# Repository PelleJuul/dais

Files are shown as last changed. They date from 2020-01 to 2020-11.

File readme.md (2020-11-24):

# The Daïs: A Haptically Enabled Electronical Instrument

A picture of the dais

The daïs is an open source *new interface for musical expression* (NIME).
The daïs main feature is a disk that is suspended by elastic string.
The instrument is played by pushing down and moving the disk around.
The position and angle of the disk is captured by sensors and can be used to control sound synthesis algorithms or audio effects.

Multiple parameters to be controlled with a single movement, and the gestures afforded by the instrument result in a performative playing style.
The disk is haptically enabled using vibrotactile transducers that facilitate an intimate playing experience.

The Daïs was presented at [NIME 2020](https://www.nime.org/proceedings/2020/nime2020_paper119.pdf) and was later featured on the [Bela blog](https://blog.bela.io/2020/10/30/dais-haptic-feedback-instrument-pelle-christensen/). See also the [video](https://www.youtube.com/watch?v=Zl-xNjUgyLA) made for the blog post.

## About this Repository

This repository contains everything you need to build your own daïs.

The *source* folder contains a ready-to-use Bela application that will read the sensors and produce a synthesized bowed string sound.

*dais_mechanical_design.scad* is an OpenSCAD file of the mechanical design of the daïs that can be used to generate files for laser cutting.

## Building a daïs

To build a daïs you will need the following tools and software

* [OpenSCAD](https://www.openscad.org/downloads.html).
* A vector drawing program such as Adobe Illustrator, CorelDraw or [Inkscape](https://inkscape.org/) (free).
* A laser cutter.
* A soldering iron.
* Misc. small tools such as scissors, cutter, and pliers.

The electronics parts you need are

* A [Bela](https://bela.io/).
* An APDS9900 breakout board (e.g. the one from [Sparkfun](https://www.sparkfun.com/products/12787)).
* A Bosch Sensortec BNO055 breakout board (e.g. [this one on ebay](https://www.ebay.com/itm/BNO055-MCU-9DOF-Intelligent-9Axis-Attitude-Sensor-Angle-gyroscope-Accelerometer/323248036779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)).
* A small stereo amplifier board ([such as this one](https://www.banggood.com/TPA3118-2x30W-8-26V-DC-Stereo-Bluetooth-Digital-Amplifier-Board-p-1095250.html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)).
* A surface transducer ([like this one](https://www.sparkfun.com/products/10975)).
* Some wire and optionally some Bela-compatible Molex connectors.

Other matrials needed are

* Solder.
* SuperGlue.
* Strips.
* Elastic string, 1m, around 3mm in diameter.
* Leather straps or string, around 2m.
* Duct tape (don't know for what exactly but you will probably need it).

The parts and materials should be assembled like so:

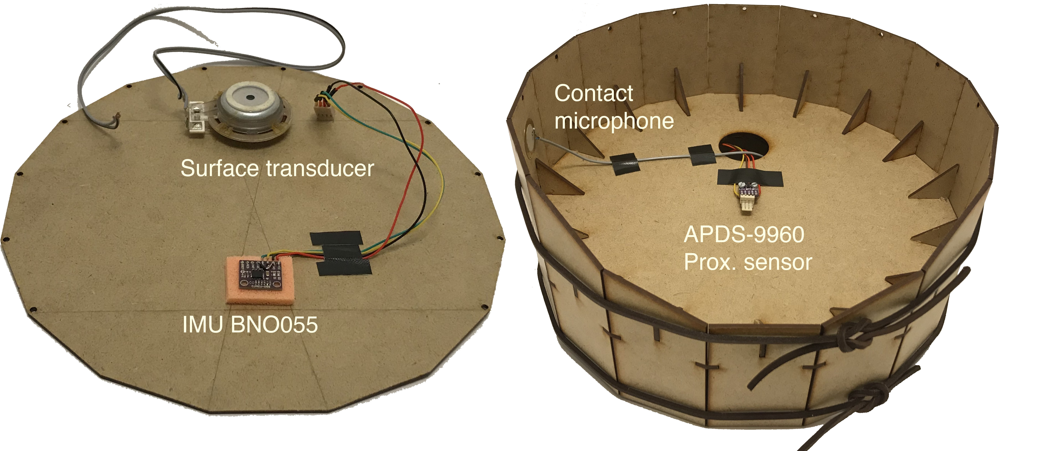
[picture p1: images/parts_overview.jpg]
Picture with an overview of the placements of the parts


## Whish list

This repository is far from perfect, these are the things needed to make it good:

* Add desciption on how to get the source code onto the bela (use the *push* script in the *source* folder)
* Add descriptions of the parameter mapping of the software.
* Add the paper (when its done).
* Through build instruct with step-by-step pictures.
* Clean up code and add comments.
* Make a video of the build process and the instrument being played.

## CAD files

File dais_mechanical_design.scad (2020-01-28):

// CHECK BEFORE PRINTING:
// - Are all dimensions correct?
// - Is material thickness correct?
// - Is kerf correct?
$fn = 50;

mt = 3; // Material thickness
// Kerf tip: Keep fingers the "right" size and make the slots a big smaller.
kerf = 0.125;
explode = false;
kc = 2; // Knoll clearance

numFaces = 16; // Number of edges on base plate
baseRadius = 150;
diskRadius = baseRadius - 20;

// If we call ngon directly with the specified baseRadius our disk will be too small.
// We want baseRadius to be the distance from the center to the middle of one of the edges.
// Here we compute the radius we need to acheive that.
trueBaseRadius = baseRadius * (1 / cos(0.5 * (360 / numFaces)));
trueDiskRadius = diskRadius * (1 / cos(0.5 * (360 / numFaces)));

wallUpper = 80; // Upper height of wall
wallLower = 60; // Lower hight of wall
wallWidth = norm([trueBaseRadius - mt, 0] - [(trueBaseRadius - mt) * cos(360 / numFaces), (trueBaseRadius- mt) * sin(360 / numFaces)]);
wallMiddleWidth = 0.8 * wallWidth;
wallSupportWidth = 30;
cutoutHeight = 1 - wallSupportWidth / wallUpper;
cutoutWidth = 5 * (1 / numFaces);
wireRadius = 1.5;
mountHeight = mt;
routingHoleRadius = 20;

function ex(enable) = (enable && explode) ? explodeAmount : 0;
function cutout(x, w, h) = x < w ? 1 - h * sin(180 * (x / w)) : 1;

module mount(tool = false, knoll = false)
{
    module mountInner()
    {
        union()
        {
            translate([-(baseRadius - mt), 0, 0])
            translate([-mt, -0.5 * 0.5 * wallWidth, 0])
            cube([mt, 0.5 * wallWidth, mt]);

            translate([baseRadius - mt, 0, 0])
            translate([0, -0.5 * 0.5 * wallWidth, 0])
            cube([mt, 0.5 * wallWidth, mt]);

            translate([-(baseRadius - mt), -0.5 * wallWidth, 0])
                cube([2 * baseRadius - 2 * mt, wallWidth, mt]);
        }
    }
    
    if (tool)
    {
        w = 0.5 * wallWidth - 2 * kerf;
        h = mt - 2 * kerf;
        translate([0, 0, mountHeight])
        translate([0, 0.5 * (wallWidth - w), 0])
        translate([0, 0, 0.5 * (mt - h)])
            cube([mt, w, h]);

    }
    else
    {
        color("pink")
        
        if (knoll)
        {
            translate([(trueBaseRadius + mt), 0.5 * wallWidth, 0]) 
            mountInner();
        }
        else
        {
            rotate([0, 0, -2 * (360 / numFaces)])
            translate([0, 0, mountHeight])
                mountInner();
        }
    }
}
module ngon(numFaces, radius, height)
{
    p = [for (i = [0:numFaces-1]) [radius * cos(i * (360 / numFaces)), radius * sin(i * (360 / numFaces))]];
    echo(p);
    linear_extrude(height)
        polygon(p);
}

module wallSupport(tool = false, knoll = false)
{   
    e = ex(!tool);

    width = wallSupportWidth;
    height = width;
    k = tool ? kerf : 0;
    fingerLength = (width * 0.5) - (tool ? 2 * kerf : 0);
    fingerWidth = mt - (tool ? 2 * kerf : 0);
    fingerHeight = mt;
    
    module finger()
    {
        translate([0, 0.5 * (mt - fingerWidth), 0]) // Center on part y axis (in case this is a tool)
        translate([-fingerLength - 0.5 * (width - fingerLength), 0, 0]) // Center on part x axis
        translate([0, 0, -fingerHeight]) // Flush with x axis
        cube([fingerLength, fingerWidth, fingerHeight]);
    }
    
    color("pink")
    union()
    {
        if (true)
        {
            rotate([-90, 0, 0]) // Turn upright
            linear_extrude(mt)
                polygon([[0, 0], [0, -height], [-width, 0]]);
        }
        
        finger();
        
        translate([fingerHeight, 0, 0])
        rotate([0, 90, 0])
            finger();
    }
}

module wall(a = wallUpper, b = wallUpper, slot = false, tool = false)
{
    if (tool)
    {
        
        translate([0, 0.5 * (wallWidth - (wallMiddleWidth - 2 * kerf)), wallLower])
                cube([mt, wallMiddleWidth - 2 * kerf, mt]);
    }
    else
    {
        difference()
        {
            union()
            {
                // Lower part
                cube([mt, wallWidth, wallLower + kerf]);
                
                // Middle part
                translate([0, 0.5 * (wallWidth - wallMiddleWidth), wallLower + kerf])
                    cube([mt, wallMiddleWidth, mt - 2 * kerf]);
                
                // Upper part
                translate([0, 0, wallLower + mt - kerf])
                translate([mt, 0, 0])
                rotate([0, -90, 0])
                linear_extrude(mt)
                polygon([
                    [0, 0],
                    [a, 0],
                    [b, wallWidth],
                    [0, wallWidth]]);
            }
            
            // Hole for wire
            if (a == b && a == wallUpper)
            {
                translate([0, 0, wallLower + mt - kerf + 0.5 * (a + b) - 2 * wireRadius])
                translate([0, 0.5 * wallWidth, 0])
                rotate([0, 90, 0]) // Rotate to correct orientation
                cylinder(mt, wireRadius, wireRadius);
            }
            
            translate([0, 0, wallLower + mt - kerf]) // Move to meet base plate
            translate([0, 0.5 * wallWidth, 0]) // Center on wall
            translate([0, -0.5 * mt, 0]) // Center on y-axis
                wallSupport(tool = true);
            
            if (slot)
            {
                mount(tool = true);
            }
        }
    }
}

module wallWithSupport(a, b, slot, tool = false, knoll = false)
{
    wall(a, b, slot, tool);
    
    if (tool)
    {
        translate([0, 0, wallLower + mt]) // Move to meet base plate
        translate([0, 0.5 * wallWidth, 0]) // Center on wall
        translate([0, -0.5 * mt, 0]) // Center on y-axis
            wallSupport(tool);
    }
    else
    {
        if (knoll)
        {
            translate([0, 0, wallLower + mt + max(a, b) + kc - kerf])
            translate([0, mt, mt])
            rotate([0, 0, -90])
                wallSupport(tool);
        }
        else
        {
            translate([0, 0, wallLower + mt - kerf]) // Move to meet base plate
            translate([0, 0.5 * wallWidth, 0]) // Center on wall
            translate([0, -0.5 * mt, 0]) // Center on y-axis
                wallSupport(tool);
        }
    }
}

module walls(tool = false, knoll = false)
{
    for (i = [0:numFaces-1])
    {
        a = i * (360 / numFaces);
        x1 = i / numFaces;
        x2 = (i+1)/ numFaces;
        echo(x1, x2);
        h1 = wallUpper * cutout(x1, cutoutWidth, cutoutHeight);
        h2 = wallUpper * cutout(x2, cutoutWidth, cutoutHeight);
        
        if (knoll)
        {
            translate([0, 0, mt])
            translate([0, i * (wallWidth + kc), 0])
            rotate([0, 90, 0])
                wallWithSupport(h1, h2, i == 6 || i == numFaces - 2, tool, knoll=true);
        }
        else
        {

            rotate([0, 0, a]) // Rotate to appropriate edge
            translate([-mt, 0, 0]) // Move flush to edge
            translate([baseRadius, 0, 0]) // Move to edge of base plate
            translate([0, -0.5 * wallWidth, 0]) // center on y axis
                wallWithSupport(h1, h2, i == 6 || i == numFaces - 2, tool);
        }
    }
}

module base()
{     
    color("green")
    
    difference()
    {
        rotate([0, 0, 0.5 * (360 / numFaces)])
            ngon(numFaces, trueBaseRadius, mt);
        
        translate([0, 0, -wallLower]) // Move down to collide with base
            walls(tool = true);
        
        translate([-0.3 * trueBaseRadius, -0.3 * trueBaseRadius, 0, ])
            cylinder(mt,routingHoleRadius, routingHoleRadius);
        
        // Cutouts for proximity sensor
        rotate([0, 0, -45])
        {
            translate([-4.5, 0, 0])
                cylinder(mt, 1.5, 1.5);
            translate([4.5, 0, 0])
                cylinder(mt, 1.5, 1.5);
        }
    }
}

module disk()
{
    rotate([0, 0, 0.5 * (360 / numFaces)])
    difference()
    {
        ngon(numFaces, trueDiskRadius, mt);
        
        for (i = [4:numFaces-1])
        {
            rotate([0, 0, i * (360 / numFaces)])
            translate([trueDiskRadius - 2 * wireRadius, 0, 0])
                cylinder(mt, wireRadius, wireRadius);
        }
    }
}

// The knoll flag enables layout of all the parts for laser cutting. Set to
// false to see a 3D model of the dais design.
knoll = true;

if (knoll)
{
    projection()
    {
        walls(knoll = true);
        x1 = wallLower + wallUpper + mt - kerf + wallSupportWidth + 2 * kc;
        translate([x1, 0, 0])
            mount(knoll = true);
        
        x2 = x1 + kc + 2 * trueBaseRadius + baseRadius + 2 * mt;
        
        translate([x2, baseRadius, 0])
            base();
        
        x3 = x2 + kc + 2 * baseRadius;
        translate([x3, diskRadius, 0])
        disk();
    }
}
else
{
    walls();
    mount();
    translate([0, 0, wallLower])
        base();
    translate([0, 0, wallLower + mt + wallUpper])
        disk();    
}
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

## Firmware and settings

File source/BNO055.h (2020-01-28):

/***************************************************************************
  This is a library for the BNO055 orientation sensor
  Designed specifically to work with the Adafruit BNO055 Breakout.
  Pick one up today in the adafruit shop!

  ------> http://www.adafruit.com/products

  These sensors use I2C to communicate, 2 pins are required to interface.

  Adafruit invests time and resources providing this open source code,
  please support Adafruit andopen-source hardware by purchasing products
  from Adafruit!

  Written by KTOWN for Adafruit Industries.
  Modified for operation on a linux platform by William Gerhard

  MIT license, all text above must be included in any redistribution
 ***************************************************************************/

#ifndef _BNO055_H
#define _BNO055_H
#include <stdint.h>
#include "I2C.h"
#include "imumaths.h"

// Register Definitions

#define BNO055_ADDRESS_A (0x28)
#define BNO055_ADDRESS_B (0x29)
#define BNO055_ID        (0xA0)

#define NUM_BNO055_OFFSET_REGISTERS (22)

typedef struct
{
    uint16_t accel_offset_x;
    uint16_t accel_offset_y;
    uint16_t accel_offset_z;
    uint16_t gyro_offset_x;
    uint16_t gyro_offset_y;
    uint16_t gyro_offset_z;
    uint16_t mag_offset_x;
    uint16_t mag_offset_y;
    uint16_t mag_offset_z;

    uint16_t accel_radius;
    uint16_t mag_radius;
} bno055_offsets_t;

//! Main class that exports features for BNO055 chip
class BNO055 {
public:

 typedef enum
    {
      /* Page id register definition */
      BNO055_PAGE_ID_ADDR                                     = 0X07,

      /* PAGE0 REGISTER DEFINITION START*/
      BNO055_CHIP_ID_ADDR                                     = 0x00,
      BNO055_ACCEL_REV_ID_ADDR                                = 0x01,
      BNO055_MAG_REV_ID_ADDR                                  = 0x02,
      BNO055_GYRO_REV_ID_ADDR                                 = 0x03,
      BNO055_SW_REV_ID_LSB_ADDR                               = 0x04,
      BNO055_SW_REV_ID_MSB_ADDR                               = 0x05,
      BNO055_BL_REV_ID_ADDR                                   = 0X06,

      /* Accel data register */
      BNO055_ACCEL_DATA_X_LSB_ADDR                            = 0X08,
      BNO055_ACCEL_DATA_X_MSB_ADDR                            = 0X09,
      BNO055_ACCEL_DATA_Y_LSB_ADDR                            = 0X0A,
      BNO055_ACCEL_DATA_Y_MSB_ADDR                            = 0X0B,
      BNO055_ACCEL_DATA_Z_LSB_ADDR                            = 0X0C,
      BNO055_ACCEL_DATA_Z_MSB_ADDR                            = 0X0D,

      /* Mag data register */
      BNO055_MAG_DATA_X_LSB_ADDR                              = 0X0E,
      BNO055_MAG_DATA_X_MSB_ADDR                              = 0X0F,
      BNO055_MAG_DATA_Y_LSB_ADDR                              = 0X10,
      BNO055_MAG_DATA_Y_MSB_ADDR                              = 0X11,
      BNO055_MAG_DATA_Z_LSB_ADDR                              = 0X12,
      BNO055_MAG_DATA_Z_MSB_ADDR                              = 0X13,

      /* Gyro data registers */
      BNO055_GYRO_DATA_X_LSB_ADDR                             = 0X14,
      BNO055_GYRO_DATA_X_MSB_ADDR                             = 0X15,
      BNO055_GYRO_DATA_Y_LSB_ADDR                             = 0X16,
      BNO055_GYRO_DATA_Y_MSB_ADDR                             = 0X17,
      BNO055_GYRO_DATA_Z_LSB_ADDR                             = 0X18,
      BNO055_GYRO_DATA_Z_MSB_ADDR                             = 0X19,

      /* Euler data registers */
      BNO055_EULER_H_LSB_ADDR                                 = 0X1A,
      BNO055_EULER_H_MSB_ADDR                                 = 0X1B,
      BNO055_EULER_R_LSB_ADDR                                 = 0X1C,
      BNO055_EULER_R_MSB_ADDR                                 = 0X1D,
      BNO055_EULER_P_LSB_ADDR                                 = 0X1E,
      BNO055_EULER_P_MSB_ADDR                                 = 0X1F,

      /* Quaternion data registers */
      BNO055_QUATERNION_DATA_W_LSB_ADDR                       = 0X20,
      BNO055_QUATERNION_DATA_W_MSB_ADDR                       = 0X21,
      BNO055_QUATERNION_DATA_X_LSB_ADDR                       = 0X22,
      BNO055_QUATERNION_DATA_X_MSB_ADDR                       = 0X23,
      BNO055_QUATERNION_DATA_Y_LSB_ADDR                       = 0X24,
      BNO055_QUATERNION_DATA_Y_MSB_ADDR                       = 0X25,
      BNO055_QUATERNION_DATA_Z_LSB_ADDR                       = 0X26,
      BNO055_QUATERNION_DATA_Z_MSB_ADDR                       = 0X27,

      /* Linear acceleration data registers */
      BNO055_LINEAR_ACCEL_DATA_X_LSB_ADDR                     = 0X28,
      BNO055_LINEAR_ACCEL_DATA_X_MSB_ADDR                     = 0X29,
      BNO055_LINEAR_ACCEL_DATA_Y_LSB_ADDR                     = 0X2A,
      BNO055_LINEAR_ACCEL_DATA_Y_MSB_ADDR                     = 0X2B,
      BNO055_LINEAR_ACCEL_DATA_Z_LSB_ADDR                     = 0X2C,
      BNO055_LINEAR_ACCEL_DATA_Z_MSB_ADDR                     = 0X2D,

      /* Gravity data registers */
      BNO055_GRAVITY_DATA_X_LSB_ADDR                          = 0X2E,
      BNO055_GRAVITY_DATA_X_MSB_ADDR                          = 0X2F,
      BNO055_GRAVITY_DATA_Y_LSB_ADDR                          = 0X30,
      BNO055_GRAVITY_DATA_Y_MSB_ADDR                          = 0X31,
      BNO055_GRAVITY_DATA_Z_LSB_ADDR                          = 0X32,
      BNO055_GRAVITY_DATA_Z_MSB_ADDR                          = 0X33,

      /* Temperature data register */
      BNO055_TEMP_ADDR                                        = 0X34,

      /* Status registers */
      BNO055_CALIB_STAT_ADDR                                  = 0X35,
      BNO055_SELFTEST_RESULT_ADDR                             = 0X36,
      BNO055_INTR_STAT_ADDR                                   = 0X37,

      BNO055_SYS_CLK_STAT_ADDR                                = 0X38,
      BNO055_SYS_STAT_ADDR                                    = 0X39,
      BNO055_SYS_ERR_ADDR                                     = 0X3A,

      /* Unit selection register */
      BNO055_UNIT_SEL_ADDR                                    = 0X3B,
      BNO055_DATA_SELECT_ADDR                                 = 0X3C,

      /* Mode registers */
      BNO055_OPR_MODE_ADDR                                    = 0X3D,
      BNO055_PWR_MODE_ADDR                                    = 0X3E,

      BNO055_SYS_TRIGGER_ADDR                                 = 0X3F,
      BNO055_TEMP_SOURCE_ADDR                                 = 0X40,

      /* Axis remap registers */
      BNO055_AXIS_MAP_CONFIG_ADDR                             = 0X41,
      BNO055_AXIS_MAP_SIGN_ADDR                               = 0X42,
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

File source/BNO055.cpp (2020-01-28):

/***************************************************************************
  This is a library for the BNO055 orientation sensor
  Designed specifically to work with the Adafruit BNO055 Breakout.
  Pick one up today in the adafruit shop!

  ------> http://www.adafruit.com/products

  These sensors use I2C to communicate, 2 pins are required to interface.

  Adafruit invests time and resources providing this open source code,
  please support Adafruit andopen-source hardware by purchasing products
  from Adafruit!

  Written by KTOWN for Adafruit Industries.
  Modified for operation on a linux platform by William Gerhard

  MIT license, all text above must be included in any redistribution
 ***************************************************************************/

#include <sys/stat.h>
#include <sys/ioctl.h>
#include <unistd.h>
#include <linux/i2c-dev.h>
#include <stdio.h>      /* Standard I/O functions */
#include <fcntl.h>
#include <syslog.h>		/* Syslog functionallity */
#include <inttypes.h>
#include <errno.h>
#include <math.h>

#include "BNO055.h"

//! Constructor takes bus and address arguments
/*!
 \param bus the bus to use in /dev/i2c-%d.
 \param address the device address on bus
 */
BNO055::BNO055(int32_t sensorID, int address, int bus)
{
	i2c = new I2C(bus,address);
  _sensorID = sensorID;
  _address = address;
  delete i2c;

	i2c = new I2C(bus,address);
  _sensorID = sensorID;
  _address = address;
	

}

BNO055::~BNO055() {
	delete i2c;
}



bool BNO055::begin(bno055_opmode_t mode)
{

	setMode(OPERATION_MODE_CONFIG);
	i2c->write_byte(BNO055_PAGE_ID_ADDR, 0);

  /* Make sure we have the right device */
  uint8_t id = i2c->read_byte(BNO055_CHIP_ID_ADDR);
  if(id != BNO055_ID)
  {
    
    id = i2c->read_byte(BNO055_CHIP_ID_ADDR);
    if(id != BNO055_ID) {
    	rt_printf("Unexpected device ID (expected %i, got %i)\n", BNO055_ID, id);
      return false;  // still not? ok bail
    }
  }

  /* Switch to config mode (just in case since this is the default) */
  setMode(OPERATION_MODE_CONFIG);

  i2c->write_byte(BNO055_SYS_TRIGGER_ADDR, 0x20);
  
  int count = 0;
  
  while (i2c->read_byte(BNO055_CHIP_ID_ADDR) != BNO055_ID)
  {
    rt_printf("Waiting for chip to reset\n");
    usleep((int)(0.1 * 10e6));
    
    count++;
    
    if (count >= 10)
    {
    	rt_printf("Failed to read ID after reset\n");
    	return false;
    }
  }
  
  usleep(50000);

  i2c->write_byte(BNO055_PAGE_ID_ADDR, 0);

  // Trigger self test
  i2c->write_byte(BNO055_SYS_TRIGGER_ADDR, 0x1);
  usleep(50000);

  uint8_t status, result, error = 0;

    getSystemStatus(&status, &result, &error);
    rt_printf("Status: %i %i %i\n", status, result & 0x0F, error);
  
  if (error != 0)
  {
  	rt_printf("Self test failed\n");
    return false;
  }
    
  i2c->write_byte(BNO055_SYS_TRIGGER_ADDR, 0x0);
  
    /* Set to normal power mode */
  i2c->write_byte(BNO055_PWR_MODE_ADDR, POWER_MODE_NORMAL);
  
  /* Set the requested operating mode (see section 3.3) */
  setMode(mode);
 
  return true;
}



void BNO055::setMode(bno055_opmode_t mode)
{
  _mode = mode;
  i2c->write_byte(BNO055_OPR_MODE_ADDR, _mode);
  usleep(30000);
}


void BNO055::setExtCrystalUse(bool usextal)
{
  bno055_opmode_t modeback = _mode;

  /* Switch to config mode (just in case since this is the default) */
  setMode(OPERATION_MODE_CONFIG);
  
  i2c->write_byte(BNO055_PAGE_ID_ADDR, 0);
  if (usextal) {
    i2c->write_byte(BNO055_SYS_TRIGGER_ADDR, 0x80);
  } else {
    i2c->write_byte(BNO055_SYS_TRIGGER_ADDR, 0x00);
  }

  /* Set the requested operating mode (see section 3.3) */
  setMode(modeback);

}


void BNO055::getSystemStatus(uint8_t *system_status, uint8_t *self_test_result, uint8_t *system_error)
{
  i2c->write_byte(BNO055_PAGE_ID_ADDR, 0);

  /* System Status (see section 4.3.58)
     ---------------------------------
     0 = Idle
     1 = System Error
     2 = Initializing Peripherals
     3 = System Iniitalization
     4 = Executing Self-Test
     5 = Sensor fusio algorithm running
     6 = System running without fusion algorithms */

  if (system_status != 0)
    *system_status    = i2c->read_byte(BNO055_SYS_STAT_ADDR);

  /* Self Test Results (see section )
     --------------------------------
     1 = test passed, 0 = test failed
     Bit 0 = Accelerometer self test
     Bit 1 = Magnetometer self test
     Bit 2 = Gyroscope self test
     Bit 3 = MCU self test
     0x0F = all good! */

  if (self_test_result != 0)
    *self_test_result = i2c->read_byte(BNO055_SELFTEST_RESULT_ADDR);

  /* System Error (see section 4.3.59)
     ---------------------------------
     0 = No error
     1 = Peripheral initialization error
     2 = System initialization error
     3 = Self test result failed
     4 = Register map value out of range
     5 = Register map address out of range
     6 = Register map write error
     7 = BNO low power mode not available for selected operat ion mode
     8 = Accelerometer power mode not available
     9 = Fusion algorithm configuration error
     A = Sensor configuration error */

  if (system_error != 0)
    *system_error     = i2c->read_byte(BNO055_SYS_ERR_ADDR);

  
}


void BNO055::getRevInfo(bno055_rev_info_t* info)
{
  uint8_t a, b;

  memset(info, 0, sizeof(bno055_rev_info_t));

  /* Check the accelerometer revision */
  info->accel_rev = i2c->read_byte(BNO055_ACCEL_REV_ID_ADDR);

  /* Check the magnetometer revision */
  info->mag_rev   = i2c->read_byte(BNO055_MAG_REV_ID_ADDR);

  /* Check the gyroscope revision */
  info->gyro_rev  = i2c->read_byte(BNO055_GYRO_REV_ID_ADDR);

  /* Check the SW revision */
  info->bl_rev    = i2c->read_byte(BNO055_BL_REV_ID_ADDR);

  a = i2c->read_byte(BNO055_SW_REV_ID_LSB_ADDR);
  b = i2c->read_byte(BNO055_SW_REV_ID_MSB_ADDR);
  info->sw_rev = (((uint16_t)b) << 8) | ((uint16_t)a);
}




void BNO055::getCalibration(uint8_t* sys, uint8_t* gyro, uint8_t* accel, uint8_t* mag) {
  uint8_t calData =  i2c->read_byte(BNO055_CALIB_STAT_ADDR);
  if (sys != NULL) {
    *sys = (calData >> 6) & 0x03;
  }
  if (gyro != NULL) {
    *gyro = (calData >> 4) & 0x03;
  }
  if (accel != NULL) {
    *accel = (calData >> 2) & 0x03;
  }
  if (mag != NULL) {
    *mag = calData & 0x03;
  }
}


int8_t BNO055::getTemp(void)
{
  int8_t temp = (int8_t)(i2c->read_byte(BNO055_TEMP_ADDR));
  return temp;
}
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
